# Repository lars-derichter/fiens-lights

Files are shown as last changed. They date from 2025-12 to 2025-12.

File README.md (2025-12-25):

# Fien's lights - NeoPixel LED Effects Controller

A customizable LED light effects controller for Arduino Nano with NeoPixel LED
strips, featuring multiple effects with real-time control via potentiometers and
gamma correction for perceptually smooth brightness transitions.

## Features

This project provides **8 different lighting effects** with intuitive control:

1. **Off** - All LEDs turned off
2. **White Light** - Adjustable color temperature (warm to cool white)
3. **Solid Hue** - Solid color with full hue control
4. **Pulse Hue** - Pulsing/breathing effect in selected color
5. **Chase Hue** - Single LED chasing along the strip
6. **Rainbow Fade** - Rainbow pattern with fade in/out
7. **Fire Effect** - Realistic fire simulation with 6 color palettes (classic,
   hot, toxic, purple, ice, inferno)
8. **White Flicker** - Random white flicker effect (3 LEDs at a time)

## Video

Check this video to see the completed project: https://youtu.be/B0sxnHQu-bU

## Hardware Requirements

- **Arduino Nano** (or compatible)
- **NeoPixel LED Strip** (WS2812/WS2812B) - 12 LEDs (configurable)
- **3x Potentiometers** (5kΩ or 10kΩ linear)
- **1x Push Button** (tactile switch)
- **1x 470Ω Resistor** (for LED data line protection)
- **1x Electrolytic Capacitor** (6.3V or higher, for power stability)
  - 220µF - 470µF: Suitable for ≤12 LEDs
  - 1000µF: Recommended for larger setups or longer wires
- **Breadboard and jumper wires**
- **Power supply** (5V, adequate for your LED strip)

## Wiring Diagram

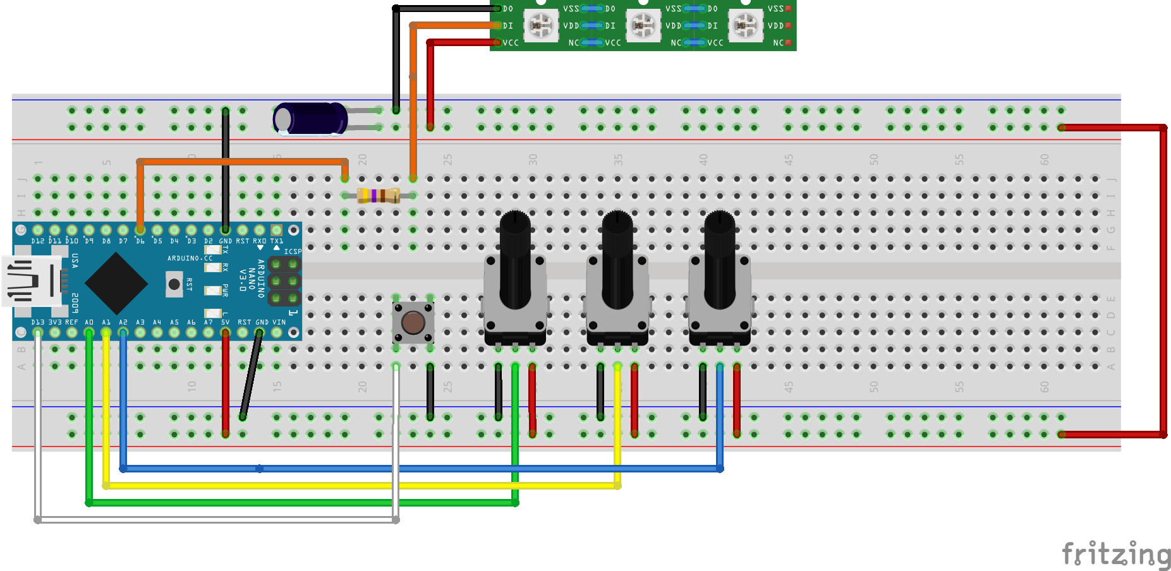
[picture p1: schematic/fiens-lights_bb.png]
Fritzing diagram of this breadboard setup


### NeoPixel LED Strip

```
Arduino Pin 6 → 470Ω Resistor → LED Strip Data Pin
LED Strip 5V                  → 5V Power Supply
LED Strip GND                 → Common Ground

Capacitor (220µF - 1000µF):
  Positive (+) → LED Strip 5V (near strip input)
  Negative (-) → LED Strip GND (near strip input)
```

_Notes:_

- _The 470Ω resistor protects the LED strip's data input and improves signal
  integrity by reducing reflections._
- _The capacitor (220µF-1000µF, 6.3V or higher) should be placed as close as
  possible to the LED strip's power input. This prevents voltage drops and
  flicker caused by sudden current surges when LEDs turn on. 220µF-470µF is
  sufficient for small setups (≤12 LEDs), while 1000µF is recommended for larger
  installations or longer wire runs._
- _**Important:** Electrolytic capacitors are polarized - connect positive (+)
  to 5V and negative (-) to GND. Reverse polarity can damage the capacitor._

### Potentiometers

```
Brightness Potentiometer (POT 1):
  Left Pin   → GND
  Center Pin → Arduino A0
  Right Pin  → 5V

Hue/Warmth Potentiometer (POT 2):
  Left Pin   → GND
  Center Pin → Arduino A1
  Right Pin  → 5V

Speed Potentiometer (POT 3):
  Left Pin   → GND
  Center Pin → Arduino A2
  Right Pin  → 5V
```

_Note: This wiring gives intuitive left-to-right control (0→1023). You can
reverse GND/5V if you prefer the opposite direction._

### Push Button

```
Button Pin 1 → Arduino Pin 2
Button Pin 2 → GND
```

_Note: The code uses the internal pull-up resistor, so no external resistor is
needed._

### Power

```
Arduino 5V  → 5V Power Supply
Arduino GND → Common Ground
```

**Important:** For LED strips with more than a few LEDs, use an external 5V
power supply (not USB power) to avoid overloading the Arduino.

## Software Setup

### Required Libraries

- **Adafruit NeoPixel** - Install via Arduino Library Manager or PlatformIO

### Installation

1. **Clone or download this repository**

   ```bash
   git clone <repository-url>
   ```

2. **Open in PlatformIO or Arduino IDE**

   - For PlatformIO: Open the project folder
   - For Arduino IDE: Open `src/main.cpp` (rename to `.ino` if needed)

3. **Install dependencies**

   - PlatformIO will auto-install from `platformio.ini`
   - Arduino IDE: Install "Adafruit NeoPixel" library

4. **Configure LED count** (if different from 12)

   - Edit `LED_COUNT` in `main.cpp` (line 6)

5. **Upload to Arduino Nano**

## Controls

### Button Control

- **Single Press**: Cycle through effects (0 → 1 → 2 → 3 → 4 → 5 → 6 → 7 → 0...)
- Effect changes are indicated in the Serial Monitor

### Potentiometer Controls

| Potentiometer  | Pin | Function |
| --- | --- | --- |
| **Brightness** | A0  | Controls overall brightness (0-255) for all effects |
| **Hue/Warmth** | A1  | Effect-dependent:<br>• White Light: Color temperature (warm to cool)<br>• Other effects: Color hue selection |
| **Speed** | A2  | Controls animation speed (10-1000ms delay, left = slowest) |

## Effect Details

### Effect 0: Off

- Turns off all LEDs
- No potentiometer controls active

### Effect 1: White Light

- **Brightness (A0)**: Adjusts light intensity
- **Warmth (A1)**: Color temperature control
  - Low (0): Very warm candlelight (orange glow)
  - Mid (512): Warm white
  - High (1023): Cool daylight (bluish white)
- **Speed (A2)**: Not used
- **8-point color temperature gradient** (5 warm, 3 cool)

### Effect 2: Solid Hue

- **Brightness (A0)**: Adjusts light intensity
- **Hue (A1)**: Full color spectrum selection
- **Speed (A2)**: Not used
- Displays a solid color across all LEDs

### Effect 3: Pulse Hue

- **Brightness (A0)**: Sets maximum brightness for pulse
- **Hue (A1)**: Color selection
- **Speed (A2)**: Pulse speed (breathing rate)
- Smoothly fades in and out

### Effect 4: Chase Hue

- **Brightness (A0)**: LED brightness
- **Hue (A1)**: Color selection
- **Speed (A2)**: Chase speed
- Single LED moves along the strip

### Effect 5: Rainbow Fade

- **Brightness (A0)**: Sets maximum brightness for fade
- **Hue (A1)**: Not used (automatic rainbow)
- **Speed (A2)**: Fade and rotation speed
- Rainbow pattern that rotates and fades

### Effect 6: Fire Effect

- **Brightness (A0)**: Overall fire intensity
- **Hue (A1)**: Selects fire color palette (6 options):
  - **Classic Fire** (pot low): Red → Orange → Yellow (traditional campfire)
  - **Hot Fire**: Orange → Yellow → White (intense heat)
  - **Toxic Fire**: Green → Cyan → Blue (chemical/magical flame)
  - **Purple Fire**: Purple → Magenta → Pink (mystical fire)
  - **Ice Fire**: Blue → Cyan → White (cold flame)
  - **Inferno** (pot high): Dark Red → Red → Orange (deep volcanic fire)
- **Speed (A2)**: Flicker rate (lower = slower flicker, higher = rapid flicker)
- Simulates realistic fire with:
  - Position-based color gradient (bottom LEDs = inner fire color, top LEDs =
    outer flame color)
  - Random brightness flickering (60-100% variation)
  - Occasional deep dimming (30% chance) for dynamic effect

### Effect 7: White Flicker

- **Brightness (A0)**: Flicker intensity
- **Hue (A1)**: Not used (always white)
- **Speed (A2)**: Flicker rate
- Random white flicker (3 LEDs at a time)

## Serial Monitor Debugging

Connect to the Serial Monitor (9600 baud) to see:

- Current effect name when switching
- Real-time potentiometer readings (every 1 second)
- Calculated values (brightness, hue, speed, RGB colors)
- Hardware diagnostics on startup

**Example output:**

```
Button pressed! Switching to effect 1: White Light
[White Light] Brightness pot: 512 -> 128 | Warmth pot: 300 -> RGB(255,198,147)
```

## Configuration

### Adjustable Parameters (in `main.cpp`)

```cpp
#define LED_PIN 6           // NeoPixel data pin
#define LED_COUNT 12        // Number of LEDs in strip
#define BUTTON_PIN 2        // Button pin
#define POT_PIN_BRIGHTNESS A0   // Brightness pot
#define POT_PIN_HUE A1          // Hue/warmth pot
#define POT_PIN_SPEED A2        // Speed pot

// Potentiometer calibration (adjust for your hardware)
#define POT_MIN 15          // Actual minimum value your pots reach
#define POT_MAX 1000        // Actual maximum value your pots reach
```

### Potentiometer Calibration

Due to hardware tolerances, potentiometers rarely reach the full theoretical
range of 0-1023. The `POT_MIN` and `POT_MAX` defines compensate for this margin
of error, ensuring you can access the full range of all effects (e.g., all fire
palettes, all white temperatures, full brightness range).

**To calibrate for your specific hardware:**

1. Upload the code and open Serial Monitor (9600 baud)
2. Select any effect that shows potentiometer values (e.g., Effect 2: Solid Hue)
3. Turn **each potentiometer fully counter-clockwise** and note the lowest "raw"
   value shown
4. Turn **each potentiometer fully clockwise** and note the highest "raw" value
   shown
5. Update the defines in [main.cpp](src/main.cpp) (lines 18-19):
   ```cpp
   #define POT_MIN 15    // Use the lowest value you observed
   #define POT_MAX 1000  // Use the highest value you observed
   ```

**Example Serial Monitor output:**

```
[Solid Hue] Brightness pot: 15 -> 0 | Hue pot: 15 -> 0 | Speed pot: N/A
[Solid Hue] Brightness pot: 1000 -> 255 | Hue pot: 1000 -> 65535 | Speed pot: N/A
```

In this example, the pots range from 15 to 1000 (not the theoretical 0 to 1023),
so `POT_MIN = 15` and `POT_MAX = 1000`.

**Effects improved by calibration:**

- **Fire Effect**: All 6 palettes become accessible (especially Inferno at high
  end)
- **White Light**: Full temperature range from very warm to very cool
- **All effects**: True minimum (0) and maximum (255/65535) values are reachable

### Speed Range

- Adjust in `readSpeedFromPot()` function (line 96)
- Default: `map(filtered, POT_MIN, POT_MAX, 1000, 10)` (pot left = 1000ms very
  slow, pot right = 10ms fast)
- For overall slower effects: Use higher values (e.g.,
  `map(filtered, POT_MIN, POT_MAX, 2000, 50)`)
- For overall faster effects: Use lower values (e.g.,
  `map(filtered, POT_MIN, POT_MAX, 500, 5)`)

### Smoothing

- Potentiometer readings use exponential moving average
- Adjust smoothing in helper functions (lines 47, 70, 93)
- Current: `(filtered * 7 + raw) / 8`
- More responsive: `(filtered * 3 + raw) / 4`
- More stable: `(filtered * 15 + raw) / 16`

### Gamma Correction

All effects use gamma correction (gamma=2.6) for perceptually linear brightness
transitions. This provides:

- **Smoother fades**: Pulse and Rainbow effects appear to fade evenly instead of
  changing quickly at low brightness and slowly at high brightness
- **Better color accuracy**: Color ratios remain consistent across all
  brightness levels
- **Realistic fire effect**: Low brightness flickers show better detail with
  realistic "ember glow"
- **Accurate white temperature**: The 8-point color temperature gradient
  maintains accurate warmth appearance at all brightness levels

Gamma correction is applied using `strip.gamma32(color)` in all effect
functions. This compensates for the non-linear relationship between LED power
levels and human brightness perception.

To disable gamma correction, remove or comment out the `strip.gamma32()` calls
in each effect function (see [solidHue()](src/main.cpp#L233),
[pulseHue()](src/main.cpp#L283), [chaseHue()](src/main.cpp#L344),
[rainbowFade()](src/main.cpp#L398), [fireEffect()](src/main.cpp#L554),
[whiteFastFlicker()](src/main.cpp#L590), and [whiteLight()](src/main.cpp#L196)).

### Porting to Other Arduino-Compatible Boards

This project can be easily ported to other boards (Arduino Uno, ESP32, ESP8266,
etc.):

**Step 1: Adjust pin assignments** in [src/main.cpp](src/main.cpp) (lines 5-14):

- `LED_PIN` - Any PWM-capable digital pin (not actually used for PWM, but good
  practice)
- `BUTTON_PIN` - Any digital pin with interrupt capability recommended
- `POT_PIN_*` - Any analog input pins (A0-A7 on most boards)

**Step 2: Board-specific setup:**

**Using PlatformIO:**

1. Edit `platformio.ini` and change the `board` line:
   ```ini
   [env:uno]
   board = uno  ; or esp32dev, nodemcuv2, etc.
   ```
2. PlatformIO will automatically handle board-specific compilation

**Using Arduino IDE:**

1. Select your board from **Tools → Board**
2. Verify pin assignments are valid for your board (check pinout diagram)
3. Upload as normal

**Important considerations:**

- **Memory**: Boards with less than 2KB SRAM may struggle (Arduino Uno works
  fine)
- **Voltage levels**: ESP boards use 3.3V logic - use level shifter for 5V
  NeoPixels
- **ADC resolution**: ESP32 has 12-bit ADC (0-4095) instead of 10-bit - may need
  to adjust `map()` functions or use `analogReadResolution(10)` on ESP32
- **Pin capabilities**: Not all pins support analog input or pull-up resistors

## Troubleshooting

### Button not working

- Check wiring: One side to Pin 2, other to GND
- Test by shorting Pin 2 to GND manually
- Replace button if faulty
- Check Serial Monitor for button press messages

### Potentiometer values jumping

- **ADC crosstalk**: Code includes dummy reads and settling delays
- **Hardware fixes**:
  - Add 0.1µF capacitor between each analog pin and GND (place close to Arduino
    pins, not at potentiometers)
  - Ensure solid breadboard connections
  - Use shorter wires
  - Check ground connections

### LEDs not responding

- Verify NeoPixel data pin (default: Pin 6)
- Check power supply (5V, sufficient current)
- Ensure common ground between Arduino and LED strip
- Test with simple Adafruit NeoPixel example first

### Colors not changing

- Open Serial Monitor to verify potentiometer readings
- Values should change from 0-1023 when turning pots
- If stuck at 0 or 1023, check wiring (5V, GND, center pin)

## Customization

### Adding New Effects

1. **Increment `NUM_EFFECTS`** (line 17)
2. **Create effect function** following existing patterns
3. **Add case to switch statement** in `loop()` (around line 186)
4. **Add effect name** to button press handler (around line 177)

Example skeleton:

```cpp
void myNewEffect()
{
  // Read potentiometers
  uint8_t brightness = readBrightnessFromPot();
  uint16_t hue = readHueFromPot();
  uint8_t speed = readSpeedFromPot();

  // Your effect logic here

  strip.show();
  delay(speed);
}
```

## More Information

[Adafruit NeoPixel Überguide](https://learn.adafruit.com/adafruit-neopixel-uberguide/neopixel-strips)

## Credits

- Built with Arduino and Adafruit NeoPixel library
- Designed for Arduino Nano with WS2812B LED strips
- I had some help from [Claude Code](https://claude.com/product/claude-code)
  while creating this project.

## License

This project is released into the public domain under the
[Unlicense](https://unlicense.org/).

You are free to use, modify, distribute, and do whatever you want with this
code, with no restrictions or obligations whatsoever. See the [LICENSE](LICENSE)
file for details.

---

**Enjoy your customizable LED effects!** 💡✨

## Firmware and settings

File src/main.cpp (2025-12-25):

#include <Arduino.h>
#include <Adafruit_NeoPixel.h>

// NeoPixel configuration
#define LED_PIN 6
#define LED_COUNT 12

// Button configuration
#define BUTTON_PIN 2

// Potentiometer configuration+
#define POT_PIN_BRIGHTNESS A0
#define POT_PIN_HUE A1
#define POT_PIN_SPEED A2

// Potentiometer calibration (actual min/max values due to hardware tolerance)
// Adjust these values based on your specific potentiometers
#define POT_MIN 15    // Typical low-end value (instead of 0)
#define POT_MAX 1000  // Typical high-end value (instead of 1023)

// Number of effects available
#define NUM_EFFECTS 8

Adafruit_NeoPixel strip(LED_COUNT, LED_PIN, NEO_GRB + NEO_KHZ800);

// Global variables
uint8_t currentEffect = 0;
bool lastButtonState = HIGH;
unsigned long lastDebounceTime = 0;
unsigned long debounceDelay = 50;

// --- Helper: read brightness knob and convert to brightness (0..255) ---
uint8_t readBrightnessFromPot()
{
  // Multiple dummy reads to fully settle ADC when switching pins
  for (int i = 0; i < 3; i++)
  {
    analogRead(POT_PIN_BRIGHTNESS);
  }
  delayMicroseconds(100);

  // Read raw pot value (0..1023)
  int raw = analogRead(POT_PIN_BRIGHTNESS);

  // Simple smoothing (exponential moving average)
  static int filtered = 512; // Start at mid brightness
  filtered = (filtered * 7 + raw) / 8;

  // Map actual pot range to 0..255 (NeoPixel brightness is 8-bit)
  uint8_t brightness = map(filtered, POT_MIN, POT_MAX, 0, 255);
  brightness = constrain(brightness, 0, 255); // Ensure we stay within bounds
  return brightness;
}

// --- Helper: read knob and convert to hue (0..65535) ---
uint16_t readHueFromPot()
{
  // Multiple dummy reads to fully settle ADC when switching pins
  for (int i = 0; i < 3; i++)
  {
    analogRead(POT_PIN_HUE);
  }
  delayMicroseconds(100);

  // Read raw pot value (0..1023)
  int raw = analogRead(POT_PIN_HUE);

  // Simple smoothing (exponential moving average)
  static int filtered = 0;
  filtered = (filtered * 7 + raw) / 8;

  // Map actual pot range to 0..65535 (NeoPixel HSV hue is 16-bit)
  uint32_t hue = map(filtered, POT_MIN, POT_MAX, 0, 65535);
  hue = constrain(hue, 0, 65535); // Ensure we stay within bounds
  return (uint16_t)hue;
}

// --- Helper: read speed knob and convert to delay time (10..1000ms) ---
uint16_t readSpeedFromPot()
{
  // Multiple dummy reads to fully settle ADC when switching pins
  for (int i = 0; i < 3; i++)
  {
    analogRead(POT_PIN_SPEED);
  }
  delayMicroseconds(100);

  // Read raw pot value (0..1023)
  int raw = analogRead(POT_PIN_SPEED);

  // Simple smoothing (exponential moving average)
  static int filtered = 512; // Start at mid speed
  filtered = (filtered * 7 + raw) / 8;

  // Map actual pot range to 1000..10 (delay in ms - lower = slower, higher = faster)
  uint16_t speed = map(filtered, POT_MIN, POT_MAX, 1000, 10);
  speed = constrain(speed, 10, 1000); // Ensure we stay within bounds
  return speed;
}

// Effect 0: Off
void effectOff()
{
  strip.clear();
  strip.setBrightness(0);
  strip.show();
  delay(100);
}

// Effect 1: White light with warmth control
void whiteLight()
{
  int rawBrightness = analogRead(POT_PIN_BRIGHTNESS);
  int rawWarmth = analogRead(POT_PIN_HUE);

  uint8_t brightness = readBrightnessFromPot();

  // Use hue pot to control warmth (0 = very warm, 1023 = very cool)
  // Map actual pot range to 0-1023 to ensure full temperature range is accessible
  int warmth = map(rawWarmth, POT_MIN, POT_MAX, 0, 1023);
  warmth = constrain(warmth, 0, 1023);

  // Map warmth to RGB values with 8 points (5 warm, 3 cool)
  // Point 0 (0): Very warm candlelight (255, 147, 41)
  // Point 1 (146): Warm amber (255, 169, 87)
  // Point 2 (292): Warm (255, 197, 143)
  // Point 3 (438): Soft warm (255, 214, 170)
  // Point 4 (585): Warm white (255, 241, 224) - warmest midpoint
  // Point 5 (731): Slightly cool (245, 243, 255)
  // Point 6 (877): Cool (225, 235, 255)
  // Point 7 (1023): Very cool daylight (201, 226, 255)
  uint8_t r, g, b;

  if (warmth < 146)
  {
    // Very warm to warm amber (0-146)
    r = 255;
    g = map(warmth, 0, 146, 147, 169);
    b = map(warmth, 0, 146, 41, 87);
  }
  else if (warmth < 292)
  {
    // Warm amber to warm (146-292)
    r = 255;
    g = map(warmth, 146, 292, 169, 197);
    b = map(warmth, 146, 292, 87, 143);
  }
  else if (warmth < 438)
  {
    // Warm to soft warm (292-438)
    r = 255;
    g = map(warmth, 292, 438, 197, 214);
    b = map(warmth, 292, 438, 143, 170);
  }
  else if (warmth < 585)
  {
    // Soft warm to warm white (438-585)
    r = 255;
    g = map(warmth, 438, 585, 214, 241);
    b = map(warmth, 438, 585, 170, 224);
  }
  else if (warmth < 731)
  {
    // Warm white to slightly cool (585-731)
    r = map(warmth, 585, 731, 255, 245);
    g = map(warmth, 585, 731, 241, 243);
    b = map(warmth, 585, 731, 224, 255);
  }
  else if (warmth < 877)
  {
    // Slightly cool to cool (731-877)
    r = map(warmth, 731, 877, 245, 225);
    g = map(warmth, 731, 877, 243, 235);
    b = 255;
  }
  else
  {
    // Cool to very cool (877-1023)
    r = map(warmth, 877, 1023, 225, 201);
    g = map(warmth, 877, 1023, 235, 226);
    b = 255;
  }

  // Debug output every 1000ms (1 second)
  static unsigned long lastPrint = 0;
  if (millis() - lastPrint > 1000)
  {
    Serial.print("[White Light] Brightness pot: ");
    Serial.print(rawBrightness);
    Serial.print(" -> ");
    Serial.print(brightness);
    Serial.print(" | Warmth pot: ");
    Serial.print(rawWarmth);
    Serial.print(" -> ");

    // Determine warmth range and description
    if (warmth < 146)
    {
      Serial.println("Point 0-1 (Very warm candlelight to Warm amber)");
    }
    else if (warmth < 292)
    {
      Serial.println("Point 1-2 (Warm amber to Warm)");
    }
    else if (warmth < 438)
    {
      Serial.println("Point 2-3 (Warm to Soft warm)");
    }
    else if (warmth < 585)
    {
      Serial.println("Point 3-4 (Soft warm to Warm white)");
    }
    else if (warmth < 731)
    {
      Serial.println("Point 4-5 (Warm white to Slightly cool)");
    }
    else if (warmth < 877)
    {
      Serial.println("Point 5-6 (Slightly cool to Cool)");
    }
    else
    {
      Serial.println("Point 6-7 (Cool to Very cool daylight)");
    }

    lastPrint = millis();
  }

  // Create color with gamma correction
  uint32_t color = strip.Color(r, g, b);
  color = strip.gamma32(color);

  // Set all pixels to the white color
  for (int i = 0; i < LED_COUNT; i++)
  {
    strip.setPixelColor(i, color);
  }

  strip.setBrightness(brightness);
  strip.show();
  delay(10);
}

// Effect 2: Knob controls hue (solid color)
void solidHue()
{
  int rawBrightness = analogRead(POT_PIN_BRIGHTNESS);
  int rawHue = analogRead(POT_PIN_HUE);

  uint16_t hue = readHueFromPot();
  uint8_t brightness = readBrightnessFromPot();

  // Debug output every 1000ms (1 second)
  static unsigned long lastPrint = 0;
  if (millis() - lastPrint > 1000)
  {
    Serial.print("[Solid Hue] Brightness pot: ");
    Serial.print(rawBrightness);
    Serial.print(" -> ");
    Serial.print(brightness);
    Serial.print(" | Hue pot: ");
    Serial.print(rawHue);
    Serial.print(" -> ");
    Serial.println(hue);
    lastPrint = millis();
  }

  // Full saturation & value gives vivid color
  uint32_t c = strip.ColorHSV(hue, 255, 255);

  // Gamma correction for perceptually linear brightness
  c = strip.gamma32(c);

  strip.setBrightness(brightness);

  for (int i = 0; i < LED_COUNT; i++)
  {
    strip.setPixelColor(i, c);
  }

  strip.show();
  delay(10);
}

// Effect 3: Pulse with hue control
void pulseHue()
{
  static uint8_t brightness = 0;
  static int8_t fadeAmount = 5;

  int rawBrightness = analogRead(POT_PIN_BRIGHTNESS);
  int rawHue = analogRead(POT_PIN_HUE);
  int rawSpeed = analogRead(POT_PIN_SPEED);

  uint16_t hue = readHueFromPot();
  uint8_t maxBrightness = readBrightnessFromPot();
  uint8_t speed = readSpeedFromPot();

  // Debug output every 1000ms (1 second)
  static unsigned long lastPrint = 0;
  if (millis() - lastPrint > 1000)
  {
    Serial.print("[Pulse Hue] Brightness pot: ");
    Serial.print(rawBrightness);
    Serial.print(" -> Max: ");
    Serial.print(maxBrightness);
    Serial.print(", Current: ");
    Serial.print(brightness);
    Serial.print(" | Hue pot: ");
    Serial.print(rawHue);
    Serial.print(" -> ");
    Serial.print(hue);
    Serial.print(" | Speed pot: ");
    Serial.print(rawSpeed);
    Serial.print(" -> ");
    Serial.println(speed);
    lastPrint = millis();
  }

  // Set all pixels to the selected hue
  uint32_t c = strip.ColorHSV(hue, 255, 255);
  c = strip.gamma32(c);

  for (int i = 0; i < LED_COUNT; i++)
  {
    strip.setPixelColor(i, c);
  }

  strip.setBrightness(brightness);
  strip.show();

  // Fade in and out
  brightness += fadeAmount;

  // Reverse fade direction at the ends (0 to maxBrightness)
  if (brightness <= 0 || brightness >= maxBrightness)
  {
    fadeAmount = -fadeAmount;
  }

  delay(speed);
}

// Effect 4: Chase effect with hue control
void chaseHue()
{
  static uint8_t position = 0;

  int rawBrightness = analogRead(POT_PIN_BRIGHTNESS);
  int rawHue = analogRead(POT_PIN_HUE);
  int rawSpeed = analogRead(POT_PIN_SPEED);

  uint16_t hue = readHueFromPot();
  uint8_t brightness = readBrightnessFromPot();
  uint8_t speed = readSpeedFromPot();

  // Debug output every 1000ms (1 second)
  static unsigned long lastPrint = 0;
  if (millis() - lastPrint > 1000)
  {
    Serial.print("[Chase Hue] Brightness pot: ");
    Serial.print(rawBrightness);
    Serial.print(" -> ");
    Serial.print(brightness);
    Serial.print(" | Hue pot: ");
    Serial.print(rawHue);
    Serial.print(" -> ");
    Serial.print(hue);
    Serial.print(" | Speed pot: ");
    Serial.print(rawSpeed);
    Serial.print(" -> ");
    Serial.print(speed);
    Serial.print(" | Position: ");
    Serial.println(position);
    lastPrint = millis();
  }

  // Clear all pixels
  strip.clear();

  // Set the selected hue
  uint32_t c = strip.ColorHSV(hue, 255, 255);
  c = strip.gamma32(c);

  // Light up the current position
  strip.setPixelColor(position, c);

  strip.setBrightness(brightness);
  strip.show();

  // Move to next position
  position++;
  if (position >= LED_COUNT)
  {
    position = 0;
  }

  delay(speed);
}

// Effect 5: Rainbow Fade In/Out
void rainbowFade()
{
  static uint16_t hue = 0;
  static uint8_t brightness = 0;
  static int8_t fadeAmount = 5;

  int rawBrightness = analogRead(POT_PIN_BRIGHTNESS);
  int rawSpeed = analogRead(POT_PIN_SPEED);

  // Get max brightness and speed from potentiometers
  uint8_t maxBrightness = readBrightnessFromPot();
  uint8_t speed = readSpeedFromPot();

  // Debug output every 1000ms (1 second)
  static unsigned long lastPrint = 0;
  if (millis() - lastPrint > 1000)
  {
    Serial.print("[Rainbow Fade] Brightness pot: ");
    Serial.print(rawBrightness);
    Serial.print(" -> Max: ");
    Serial.print(maxBrightness);
    Serial.print(", Current: ");
    Serial.print(brightness);
    Serial.print(" | Hue: N/A | Speed pot: ");
    Serial.print(rawSpeed);
    Serial.print(" -> ");
    Serial.println(speed);
    lastPrint = millis();
  }

  // Manually create rainbow with gamma correction
  for (int i = 0; i < LED_COUNT; i++)
  {
    uint16_t pixelHue = hue + (i * 65536L / LED_COUNT);
    uint32_t color = strip.ColorHSV(pixelHue, 255, 255);
    color = strip.gamma32(color);
    strip.setPixelColor(i, color);
  }

  strip.setBrightness(brightness);
  strip.show();

  brightness += fadeAmount;

  // Fade between 0 and the potentiometer value
  if (brightness <= 0 || brightness >= maxBrightness)
  {
    fadeAmount = -fadeAmount;
  }

  hue += 127;
  delay(speed);
}

// Effect 6: Fire Effect
void fireEffect()
{
  int rawBrightness = analogRead(POT_PIN_BRIGHTNESS);
  int rawHue = analogRead(POT_PIN_HUE);
  int rawSpeed = analogRead(POT_PIN_SPEED);

  uint8_t brightness = readBrightnessFromPot();
  uint16_t huePot = readHueFromPot();
  uint16_t speed = readSpeedFromPot();

  // Map hue pot to select fire color palette (using calibrated range -> 0-5)
  uint8_t palette = map(analogRead(POT_PIN_HUE), POT_MIN, POT_MAX, 0, 5);
  palette = constrain(palette, 0, 5); // Ensure we can reach all palettes

  // Debug output every 1000ms
  static unsigned long lastPrint = 0;
  if (millis() - lastPrint > 1000)
  {
    Serial.print("[Fire Effect] Brightness pot: ");
    Serial.print(rawBrightness);
    Serial.print(" -> ");
    Serial.print(brightness);
    Serial.print(" | Hue pot: ");
    Serial.print(rawHue);
    Serial.print(" -> Palette ");
    Serial.print(palette);
    Serial.print(" (");
    switch (palette)
    {
    case 0:
      Serial.print("Classic Fire");
      break;
    case 1:
      Serial.print("Hot Fire");
      break;
    case 2:
      Serial.print("Toxic Fire");
      break;
    case 3:
      Serial.print("Purple Fire");
      break;
    case 4:
      Serial.print("Ice Fire");
      break;
    case 5:
      Serial.print("Inferno");
      break;
    }
    Serial.print(") | Speed pot: ");
    Serial.print(rawSpeed);
    Serial.print(" -> ");
    Serial.println(speed);
    lastPrint = millis();
  }

  strip.clear();
  strip.setBrightness(brightness);

  // Color palette definitions (HSV hue values: 0-65535)
  // Each palette has 3 colors: inner (bottom), middle, outer (top)
  // Note: Values adjusted to compensate for gamma correction's effect on perceived hue
  uint16_t innerHue, middleHue, outerHue;

  switch (palette)
  {
  case 0:            // Classic Fire: Red → Orange → Yellow
    innerHue = 0;    // Red
    middleHue = 4000; // Orange (shifted more toward red)
    outerHue = 7500;  // Yellow (shifted significantly from 60° to ~41° to eliminate green)
    break;
  case 1:             // Hot Fire: Orange → Yellow → White-ish
    innerHue = 4000;  // Orange (adjusted to match classic fire middle)
    middleHue = 7500; // Yellow (adjusted to match classic fire outer)
    outerHue = 11000; // Yellow-white (much warmer)
    break;
  case 2:              // Toxic Fire: Green → Cyan → Blue
    innerHue = 22000;  // Green (slightly yellower to compensate)
    middleHue = 33000; // Cyan (slightly adjusted)
    outerHue = 43691;  // Blue (240° - unchanged)
    break;
  case 3:              // Purple Fire: Purple → Magenta → Pink
    innerHue = 49500;  // Purple (slightly adjusted)
    middleHue = 54800; // Magenta (slightly adjusted)
    outerHue = 60500;  // Pink (slightly adjusted)
    break;
  case 4:              // Ice Fire: Blue → Cyan → White-ish
    innerHue = 43691;  // Blue (240° - unchanged)
    middleHue = 33000; // Cyan (matches toxic fire middle)
    outerHue = 15000;  // Light cyan (adjusted to be cooler white)
    break;
  case 5:             // Inferno: Dark Red → Red → Orange
    innerHue = 60500; // Dark red/maroon (slightly adjusted)
    middleHue = 0;    // Red (unchanged)
    outerHue = 4500;  // Orange (matches classic fire middle)
    break;
  }

  // Draw fire on each LED
  for (int i = 0; i < LED_COUNT; i++)
  {
    // Calculate position ratio (0.0 at bottom, 1.0 at top)
    float position = (float)i / (float)(LED_COUNT - 1);

    // Select color based on position
    uint16_t hue;
    uint8_t sat = 255; // Full saturation by default

    if (position < 0.33)
    {
      // Bottom third: inner fire color
      hue = innerHue;
    }
    else if (position < 0.66)
    {
      // Middle third: blend between inner and middle
      float blend = (position - 0.33) / 0.33;
      hue = innerHue + (uint16_t)((middleHue - innerHue) * blend);
    }
    else
    {
      // Top third: blend between middle and outer
      float blend = (position - 0.66) / 0.34;
      hue = middleHue + (uint16_t)((outerHue - middleHue) * blend);
      // Reduce saturation at the tips for white-hot effect
      // Hot fire palette gets extra desaturation for whiter tips
      uint8_t satReduction = (palette == 1) ? 93 : 80;
      sat = 255 - (uint8_t)(blend * satReduction);
    }

    // Add random flicker to brightness (60-100% of set brightness)
    uint8_t flicker = random(153, 256); // 60-100% of 255
    uint8_t val = (uint8_t)((255 * flicker) / 256);

    // Additional flicker: randomly dim some LEDs more
    if (random(0, 100) < 30) // 30% chance
    {
      val = val / 2; // Dim to 50%
    }

    uint32_t color = strip.ColorHSV(hue, sat, val);
    color = strip.gamma32(color);
    strip.setPixelColor(i, color);
  }

  strip.show();
  delay(speed / 2); // Faster updates for more dynamic flicker
}

// Effect 7: White Flicker
void whiteFastFlicker()
{
  int rawBrightness = analogRead(POT_PIN_BRIGHTNESS);
  int rawSpeed = analogRead(POT_PIN_SPEED);

  uint8_t brightness = readBrightnessFromPot();
  uint8_t speed = readSpeedFromPot();

  // Debug output every 1000ms (1 second)
  static unsigned long lastPrint = 0;
  if (millis() - lastPrint > 1000)
  {
    Serial.print("[White Flicker] Brightness pot: ");
    Serial.print(rawBrightness);
    Serial.print(" -> ");
    Serial.print(brightness);
    Serial.print(" | Hue: N/A | Speed pot: ");
    Serial.print(rawSpeed);
    Serial.print(" -> ");
    Serial.println(speed);
    lastPrint = millis();
  }

  strip.clear();
  strip.setBrightness(brightness);

  uint32_t white = strip.Color(255, 255, 255);
  white = strip.gamma32(white);

  for (int i = 0; i < 3; i++)
  {
    int randomPixel = random(0, LED_COUNT);
    strip.setPixelColor(randomPixel, white);
  }

  strip.show();
  delay(speed);
}

void setup()
{
  Serial.begin(9600);

  strip.begin();
  strip.show();
  strip.setBrightness(0);

  pinMode(BUTTON_PIN, INPUT_PULLUP);

  Serial.println("Setup complete. Current effect: 0");

  // Test potentiometer wiring
  Serial.println("\n=== Potentiometer Test ===");
  Serial.println("Testing all three potentiometers...");
  for (int i = 0; i < 2; i++)
  {
    int hueValue = analogRead(POT_PIN_HUE);
    int brightnessValue = analogRead(POT_PIN_BRIGHTNESS);
    int speedValue = analogRead(POT_PIN_SPEED);
    Serial.print("Brightness (A0): ");
    Serial.print(brightnessValue);
    Serial.print(" | Hue (A1): ");
    Serial.print(hueValue);
    Serial.print(" | Speed (A2): ");
    Serial.println(speedValue);
    delay(50);
  }
  Serial.println("Expected: values should range from ~0 to ~1023");
  Serial.println("=========================\n");
}

void loop()
{
  bool reading = digitalRead(BUTTON_PIN);

  if (reading != lastButtonState)
  {
    lastDebounceTime = millis();
  }

  if ((millis() - lastDebounceTime) > debounceDelay)
  {
    static bool buttonState = HIGH;

    if (reading != buttonState)
    {
      buttonState = reading;

      if (buttonState == LOW)
      {
        currentEffect = (currentEffect + 1) % NUM_EFFECTS;

        // Show effect name
        Serial.print("Button pressed! Switching to effect ");
        Serial.print(currentEffect);
        Serial.print(": ");
        switch (currentEffect)
        {
        case 0:
          Serial.println("Off");
          break;
        case 1:
          Serial.println("White Light");
          break;
        case 2:
          Serial.println("Solid Hue");
          break;
        case 3:
          Serial.println("Pulse Hue");
          break;
        case 4:
          Serial.println("Chase Hue");
          break;
        case 5:
          Serial.println("Rainbow Fade");
          break;
        case 6:
          Serial.println("Fire Effect");
          break;
        case 7:
          Serial.println("White Flicker");
          break;
        default:
          Serial.println("Unknown");
          break;
        }

        strip.clear();
        strip.show();

        delay(300);
      }
    }
  }

  lastButtonState = reading;

  switch (currentEffect)
  {
  case 0:
    effectOff();
    break;
  case 1:
    whiteLight();
    break;
  case 2:
    solidHue();
    break;
  case 3:
    pulseHue();
    break;
  case 4:
    chaseHue();
    break;
  case 5:
    rainbowFade();
    break;
  case 6:
    fireEffect();
    break;
  case 7:
    whiteFastFlicker();
    break;

  default:
    effectOff();
    break;
  }
}

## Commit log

2025-12-22 Added resistor and capacitator for better safety and performance.
2025-12-23 Short note about placement of capacitators.
2025-12-23 Added schematic
    [fiens-lights.fzz]
2025-12-23 Note on capacitator types
2025-12-23 Moved button to pin 13 so all inputs are on the same side
    [fiens-lights.fzz]
2025-12-24 Moved button back to pin 2. Pin 13 has interference from the internal LED.
    [main.cpp]
2025-12-25 Added gamma correction to all effects
    [main.cpp]
2025-12-25 Added potentiometer calibration
